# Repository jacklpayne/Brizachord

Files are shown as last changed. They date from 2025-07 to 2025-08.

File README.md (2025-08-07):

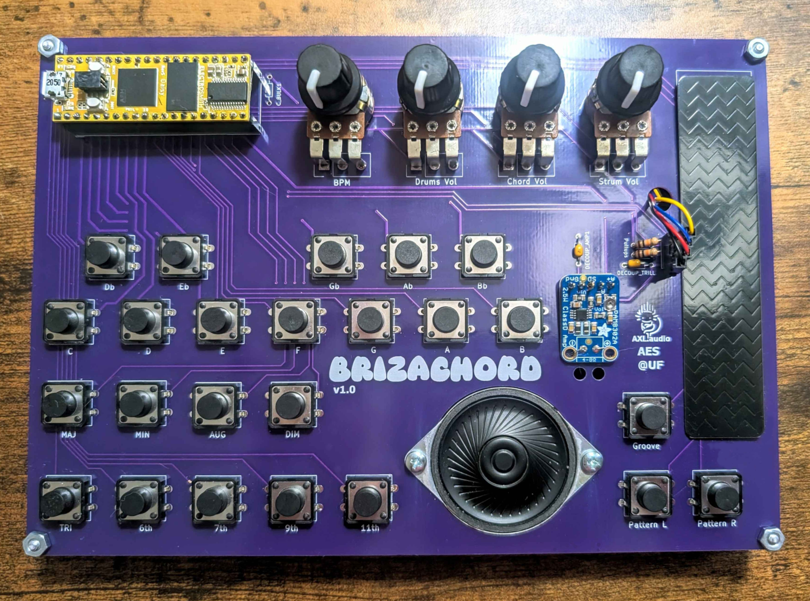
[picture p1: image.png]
Brizachord

Demo: https://www.youtube.com/watch?v=z-tGAeBtxNY

# Overview
The Brizachord is an open-source instrument and chord machine inspired by the Suzuki Omnichord. It features:
* 240 possible chords from 12 root select switches, 4 quality select switches, and 5 extension select switches
* Drum machine triggered by internal sequencer with toggleable chord pattern synchronization ("Groove"), adjustable BPM
* Velocity sensitive, multitouch capacitive strum plate for autoharp-style use
* Self-contained design with its own digital oscillators, amplification, and speaker (i.e, *not* a MIDI-only type deal).

It was designed by me and will be used in workshops held with the Audio Engineering Society at the University of Florida in Fall 2025.

# Technical
The instrument is based on the Daisy Seed audio development board and the associated `libdaisy` library for programming its STM32H7 MCU. It uses a Bela Trill Bar sensor for the strum plate and an Adafruit PAM8302A Class-D breakout for the amplifier. 

The hardware is designed for removability and reuse of the Daisy Seed and the Trill Bar.

# Future
## Software:
* Improve documentation of all functions
* USB MIDI (important)
* MIDI clock synchronization
* Data-driven CSV reading for sequencer patterns so that users can create their own more easily

## Hardware:
* Adjust Trill Bar JST cutout position
* Change corner mounting holes to M3 sized
* Find 12mm switches that are compatible with large black/white circular & square bezels to use for root selects, pattern selects
* Remove unused speaker routing holes and move Trill Bar headers to bottom of board
* Onboard power is possible, but unlikely to be implemented by me on this iteration of the board

# Environment setup
The firmware is based on a custom fork of `libdaisy` that updates the language version to `C++17` and merges @giulomoro's Trill support PR (https://github.com/electro-smith/libDaisy/pull/657). When this PR is merged upstream, the project will probably migrate to standard `libdaisy`.

# License
All software/firmware is licensed under GPLv3.
All hardware (schematic, design) is licensed under CERN-OHL-S.

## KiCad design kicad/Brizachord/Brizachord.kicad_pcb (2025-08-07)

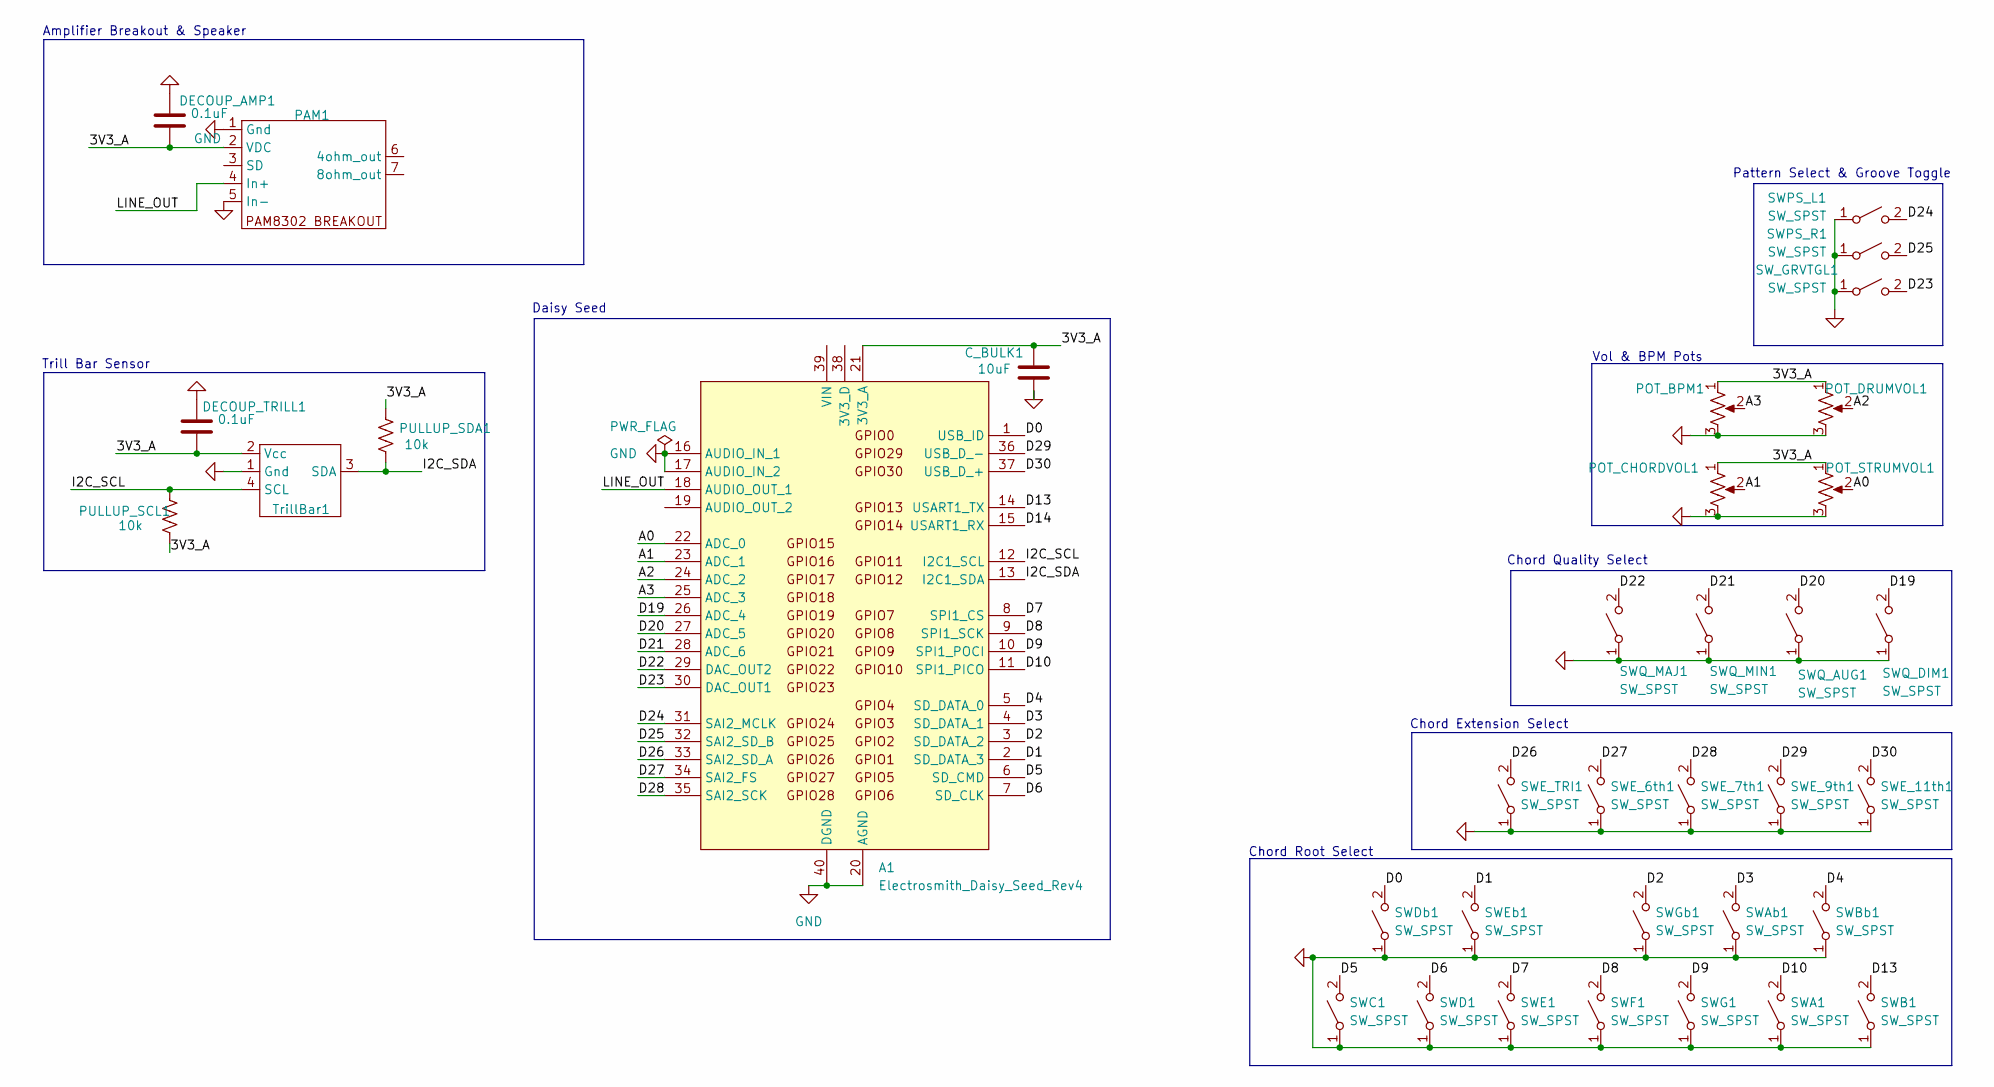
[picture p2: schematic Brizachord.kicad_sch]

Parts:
A1: Electrosmith_Daisy_Seed_Rev4; Electrosmith_Daisy_Seed
C_BULK1: 10uF; R_Axial_DIN0204_L3.6mm_D1.6mm_P7.62mm_Horizontal
DECOUP_AMP1: 0.1uF; R_Axial_DIN0204_L3.6mm_D1.6mm_P7.62mm_Horizontal
DECOUP_TRILL1: 0.1uF; R_Axial_DIN0204_L3.6mm_D1.6mm_P7.62mm_Horizontal
PAM1: PAM8302_BREAKOUT
POT_BPM1: R_Potentiometer_US; Samtec_HPM-03-01-x-S_Straight_1x03_Pitch5.08mm
POT_CHORDVOL1: R_Potentiometer_US; Samtec_HPM-03-01-x-S_Straight_1x03_Pitch5.08mm
POT_DRUMVOL1: R_Potentiometer_US; Samtec_HPM-03-01-x-S_Straight_1x03_Pitch5.08mm
POT_STRUMVOL1: R_Potentiometer_US; Samtec_HPM-03-01-x-S_Straight_1x03_Pitch5.08mm
PULLUP_SCL1: 10k; R_Axial_DIN0204_L3.6mm_D1.6mm_P5.08mm_Horizontal
PULLUP_SDA1: 10k; R_Axial_DIN0204_L3.6mm_D1.6mm_P5.08mm_Horizontal
SWA1: SW_SPST; SW_PUSH-12mm
SWAb1: SW_SPST; SW_PUSH-12mm
SWB1: SW_SPST; SW_PUSH-12mm
SWBb1: SW_SPST; SW_PUSH-12mm
SWC1: SW_SPST; SW_PUSH-12mm
SWD1: SW_SPST; SW_PUSH-12mm
SWDb1: SW_SPST; SW_PUSH-12mm
SWE1: SW_SPST; SW_PUSH-12mm
SWE_6th1, SWE_7th1, SWE_9th1, SWE_11th1: SW_SPST; SW_PUSH-12mm
SWE_TRI1: SW_SPST; SW_PUSH-12mm
SWEb1: SW_SPST; SW_PUSH-12mm
SWF1: SW_SPST; SW_PUSH-12mm
SWG1: SW_SPST; SW_PUSH-12mm
SWGb1: SW_SPST; SW_PUSH-12mm
SWPS_L1: SW_SPST; SW_PUSH-12mm
SWPS_R1: SW_SPST; SW_PUSH-12mm
SWQ_AUG1: SW_SPST; SW_PUSH-12mm
SWQ_DIM1: SW_SPST; SW_PUSH-12mm
SWQ_MAJ1: SW_SPST; SW_PUSH-12mm
SWQ_MIN1: SW_SPST; SW_PUSH-12mm
SW_GRVTGL1: SW_SPST; SW_PUSH-12mm
TrillBar1: PinHeader_1x04_P2.54mm_Vertical

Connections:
/3V3_A: A1.21 (3V3_A), C_BULK1.2, DECOUP_AMP1.1, DECOUP_TRILL1.1, PAM1.2 (VDC), POT_BPM1.1, POT_CHORDVOL1.1, POT_DRUMVOL1.1, POT_STRUMVOL1.1, PULLUP_SCL1.2, PULLUP_SDA1.1, TrillBar1.2 (Vcc)
/A0: A1.22 (ADC_0), POT_STRUMVOL1.2
/A1: A1.23 (ADC_1), POT_CHORDVOL1.2
/A2: A1.24 (ADC_2), POT_DRUMVOL1.2
/A3: A1.25 (ADC_3), POT_BPM1.2
/D0: A1.1 (USB_ID), SWDb1.2 (B)
/D1: A1.2 (SD_DATA_3), SWEb1.2 (B)
/D2: A1.3 (SD_DATA_2), SWGb1.2 (B)
/D3: A1.4 (SD_DATA_1), SWAb1.2 (B)
/D4: A1.5 (SD_DATA_0), SWBb1.2 (B)
/D5: A1.6 (SD_CMD), SWC1.2 (B)
/D6: A1.7 (SD_CLK), SWD1.2 (B)
/D7: A1.8 (SPI1_CS), SWE1.2 (B)
/D8: A1.9 (SPI1_SCK), SWF1.2 (B)
/D9: A1.10 (SPI1_POCI), SWG1.2 (B)
/D10: A1.11 (SPI1_PICO), SWA1.2 (B)
/D13: A1.14 (USART1_TX), SWB1.2 (B)
/D14: A1.15 (USART1_RX)
/D19: A1.26 (ADC_4), SWQ_DIM1.2 (B)
/D20: A1.27 (ADC_5), SWQ_AUG1.2 (B)
/D21: A1.28 (ADC_6), SWQ_MIN1.2 (B)
/D22: A1.29 (DAC_OUT2), SWQ_MAJ1.2 (B)
/D23: A1.30 (DAC_OUT1), SW_GRVTGL1.2 (B)
/D24: A1.31 (SAI2_MCLK), SWPS_L1.2 (B)
/D25: A1.32 (SAI2_SD_B), SWPS_R1.2 (B)
/D26: A1.33 (SAI2_SD_A), SWE_TRI1.2 (B)
/D27: A1.34 (SAI2_FS), SWE_6th1.2 (B)
/D28: A1.35 (SAI2_SCK), SWE_7th1.2 (B)
/D29: A1.36 (USB_D_-), SWE_9th1.2 (B)
/D30: A1.37 (USB_D_+), SWE_11th1.2 (B)
/I2C_SCL: A1.12 (I2C1_SCL), PULLUP_SCL1.1, TrillBar1.4 (SCL)
/I2C_SDA: A1.13 (I2C1_SDA), PULLUP_SDA1.2, TrillBar1.3 (SDA)
/LINE_OUT: A1.18 (AUDIO_OUT_1), PAM1.4 (In+)
GND: A1.16 (AUDIO_IN_1), A1.17 (AUDIO_IN_2), A1.20 (AGND), A1.40 (DGND), C_BULK1.1, DECOUP_AMP1.2, DECOUP_TRILL1.2, PAM1.1 (Gnd), PAM1.5 (In-), POT_BPM1.3, POT_CHORDVOL1.3, POT_DRUMVOL1.3, POT_STRUMVOL1.3, SWA1.1 (A), SWAb1.1 (A), SWB1.1 (A), SWBb1.1 (A), SWC1.1 (A), SWD1.1 (A), SWDb1.1 (A), SWE1.1 (A), SWE_6th1.1 (A), SWE_7th1.1 (A), SWE_9th1.1 (A), SWE_11th1.1 (A), SWE_TRI1.1 (A), SWEb1.1 (A), SWF1.1 (A), SWG1.1 (A), SWGb1.1 (A), SWPS_L1.1 (A), SWPS_R1.1 (A), SWQ_AUG1.1 (A), SWQ_DIM1.1 (A), SWQ_MAJ1.1 (A), SWQ_MIN1.1 (A), SW_GRVTGL1.1 (A), TrillBar1.1 (Gnd)

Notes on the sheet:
Chord Extension Select
Chord Quality Select
Vol & BPM Pots
Daisy Seed
Trill Bar Sensor
Chord Root Select
Pattern Select & Groove Toggle
Amplifier Breakout & Speaker

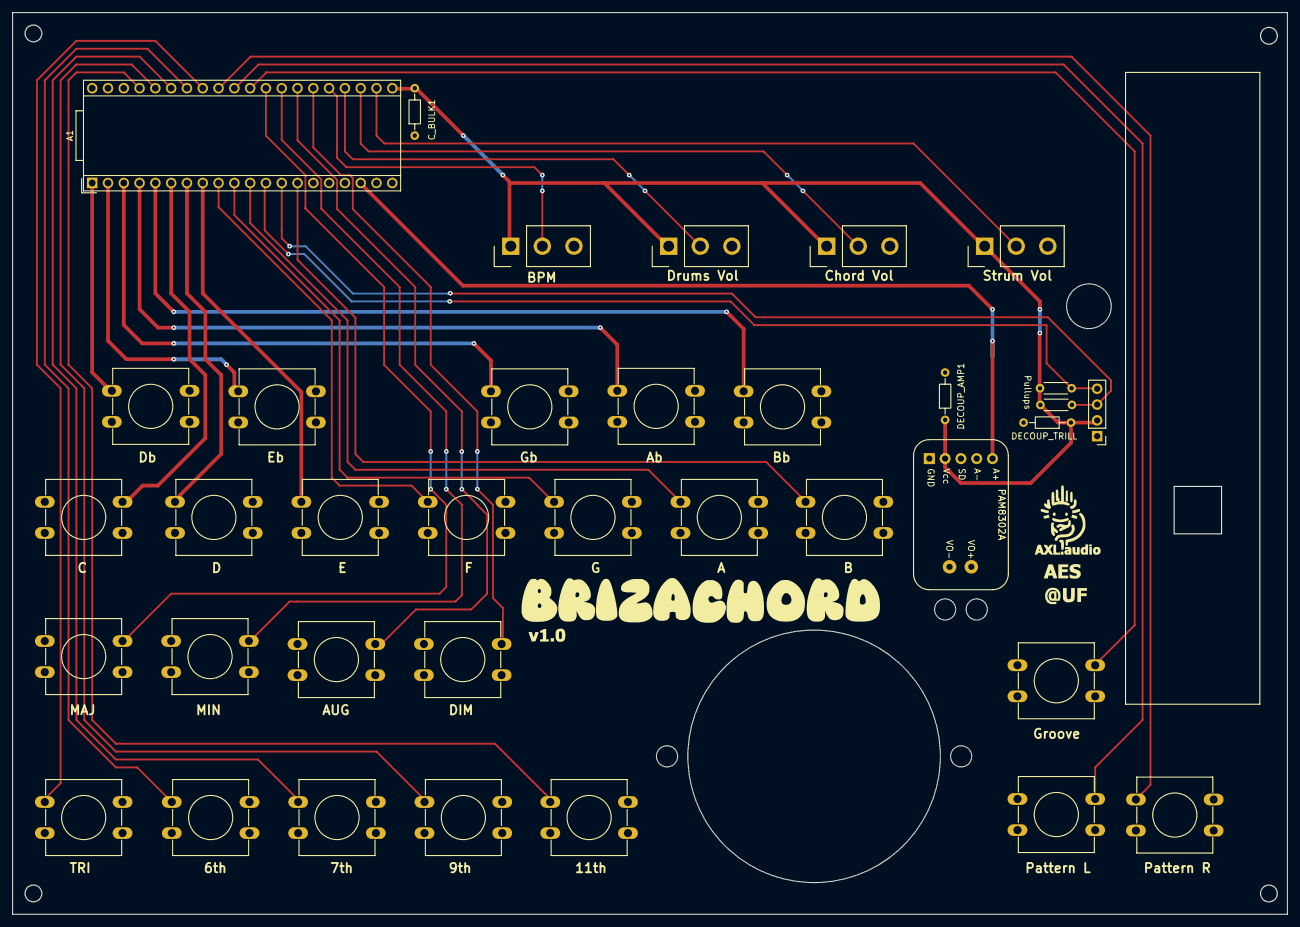
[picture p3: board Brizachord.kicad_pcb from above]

Board: 2 copper layers, 205.0 x 145.0 mm, 36 parts (0 on the bottom side), 33 nets.

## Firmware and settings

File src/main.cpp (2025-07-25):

/*
GNU General Public License v3.0
Author: Jack Payne

 _______             __                                __                                  __ 
/       \           /  |                              /  |                                /  |
BBBBBBB  |  ______  BB/  ________   ______    _______ BB |____    ______    ______    ____BB |
BB |__BB | /      \ /  |/        | /      \  /       |BB      \  /      \  /      \  /    BB |
BB    BB< /BBBBBB  |BB |BBBBBBBB/  BBBBBB  |/BBBBBBB/ BBBBBBB  |/BBBBBB  |/BBBBBB  |/BBBBBBB |
BBBBBBB  |BB |  BB/ BB |  /  BB/   /    BB |BB |      BB |  BB |BB |  BB |BB |  BB/ BB |  BB |
BB |__BB |BB |      BB | /BBBB/__ /BBBBBBB |BB \_____ BB |  BB |BB \__BB |BB |      BB \__BB |
BB    BB/ BB |      BB |/BB      |BB    BB |BB       |BB |  BB |BB    BB/ BB |      BB    BB |
BBBBBBB/  BB/       BB/ BBBBBBBB/  BBBBBBB/  BBBBBBB/ BB/   BB/  BBBBBB/  BB/        BBBBBBB/	v1.0
*/

#include "Brizachord.h"

int main(void) {
	Brizachord brizachord{};
	brizachord.main_loop();
}

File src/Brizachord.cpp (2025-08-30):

/*
GNU General Public License v3.0
Author: Jack Payne

 _______             __                                __                                  __ 
/       \           /  |                              /  |                                /  |
BBBBBBB  |  ______  BB/  ________   ______    _______ BB |____    ______    ______    ____BB |
BB |__BB | /      \ /  |/        | /      \  /       |BB      \  /      \  /      \  /    BB |
BB    BB< /BBBBBB  |BB |BBBBBBBB/  BBBBBB  |/BBBBBBB/ BBBBBBB  |/BBBBBB  |/BBBBBB  |/BBBBBBB |
BBBBBBB  |BB |  BB/ BB |  /  BB/   /    BB |BB |      BB |  BB |BB |  BB |BB |  BB/ BB |  BB |
BB |__BB |BB |      BB | /BBBB/__ /BBBBBBB |BB \_____ BB |  BB |BB \__BB |BB |      BB \__BB |
BB    BB/ BB |      BB |/BB      |BB    BB |BB       |BB |  BB |BB    BB/ BB |      BB    BB |
BBBBBBB/  BB/       BB/ BBBBBBBB/  BBBBBBB/  BBBBBBB/ BB/   BB/  BBBBBB/  BB/        BBBBBBB/	v1.0
*/

#include "Brizachord.h"
Brizachord* Brizachord::instance = nullptr;

Brizachord::Brizachord() 
	: strum_synth(48000.f, instrument_state), sequencer(48000.f, drum_synth, chord_synth)
{
    Brizachord::instance = this;

	// Hardware init
	hw.Configure();
	hw.Init();
	hw.SetAudioBlockSize(4);
	hw.SetAudioSampleRate(SaiHandle::Config::SampleRate::SAI_48KHZ);

	// Analog inputs init
	AdcChannelConfig adc_config[4];
	adc_config[0].InitSingle(hw.GetPin(15)); // A0 (Strum vol)
    adc_config[1].InitSingle(hw.GetPin(16)); // A1 (Chord vol)
    adc_config[2].InitSingle(hw.GetPin(17)); // A2 (Drums vol)
    adc_config[3].InitSingle(hw.GetPin(18)); // A3 (BPM)
	hw.adc.Init(adc_config, 4);
	hw.adc.Start();

	gpio_state.init();

	// Instrument state and oscillators init
	instrument_state.chord.root = "Bb";
	instrument_state.chord.quality = ChordQuality::MAJOR;
	instrument_state.chord.extension = ChordExtension::TRIAD;
	instrument_state.queued_extension = ChordExtension::TRIAD;
	instrument_state.queued_quality = ChordQuality::MAJOR;

	instrument_state.bpm = 80;

	auto midi_notes = chord_to_midi(instrument_state.chord);
	chord_synth.set_chord(instrument_state.chord);
	//strum_synth.set_arpeggio(midi_notes);

	poll_trill_bar();
	gpio_state.debounce_all();
	poll_chord_qual();
	poll_chord_ext();
	poll_chord_root();
	poll_pots();
	poll_pattern_controls();

	sequencer.set_bpm(instrument_state.bpm);

	hw.StartAudio(audio_callback);

	// Trill sensor setup
	// Reset I2C
    int i2cBus = 1;
    trill_bar.setup(i2cBus, Trill::BAR);
}

Brizachord::~Brizachord(){

}

void Brizachord::main_loop() {
	while(1) {
		poll_trill_bar();
		gpio_state.debounce_all();
		poll_chord_qual();
		poll_chord_ext();
		poll_chord_root();
		poll_pots();
		poll_pattern_controls();

		sequencer.set_bpm(instrument_state.bpm);
	}    
}

//======================================================================
// Main callback
//======================================================================
/* 
This callback is called every sample and:
1. Ticks the sequencer forward in time
2. Collects a sample from each of the three sound sources (chord synth, strum synth, and drums)
3. Scales them in proportion to user-set volumes and adds them together
4. Sends the resulting sample to Daisy Seed's audio output pin
*/
void Brizachord::audio_callback(AudioHandle::InputBuffer  in,
                                AudioHandle::OutputBuffer out,
                                size_t                    size) {
	
	for (size_t i = 0; i < size; i++)
	{	
		instance->sequencer.tick();
		float sample = 0.f;
		
		float chord_sample = instance->chord_synth.process();
		float drums_sample = instance->drum_synth.process();
		float strum_sample = instance->strum_synth.process();


		sample += drums_sample * 0.2f * instance->drum_vol;
		sample += chord_sample * 0.2f * instance->chord_vol;
		sample += strum_sample * 0.6f * instance->strum_vol;

		out[0][i] = sample;
		out[1][i] = sample;
	}
}

//======================================================================
// Polling
//======================================================================

/* Poll the chord root switches for changes. Update InstrumentState's chord root on a falling edge (press).*/
void Brizachord::poll_chord_root() {
    std::string new_root = instrument_state.chord.root;
	
	if      (gpio_state.button_C.FallingEdge())     new_root = "C";
	else if (gpio_state.button_Db.FallingEdge())    new_root = "Db";
	else if (gpio_state.button_D.FallingEdge())     new_root = "D";
	else if (gpio_state.button_Eb.FallingEdge())    new_root = "Eb";
	else if (gpio_state.button_E.FallingEdge())     new_root = "E";
	else if (gpio_state.button_F.FallingEdge())     new_root = "F";
	else if (gpio_state.button_Gb.FallingEdge())    new_root = "Gb";
	else if (gpio_state.button_G.FallingEdge())     new_root = "G";
	else if (gpio_state.button_Ab.FallingEdge())    new_root = "Ab";
	else if (gpio_state.button_A.FallingEdge())     new_root = "A";
	else if (gpio_state.button_Bb.FallingEdge())    new_root = "Bb";
	else if (gpio_state.button_B.FallingEdge())     new_root = "B";
	else                           return;

	if (new_root != instrument_state.chord.root) {
		instrument_state.chord.root = new_root;
		instrument_state.chord.quality = instrument_state.queued_quality;
		instrument_state.chord.extension = instrument_state.queued_extension;

		// Prevent audio ISR from being called while rebuilding the osc vectors
		__disable_irq();
		auto midi_notes = chord_to_midi(instrument_state.chord);
		chord_synth.set_chord(instrument_state.chord);
		strum_synth.set_arpeggio(midi_notes);
		__enable_irq();
	}
	else {
		instrument_state.no_chord = !instrument_state.no_chord;
	}
}

/* 
Poll the chord quality switches for changes.
On falling edge (press): update the InstrumentState's queued chord quality.
On rising edge (release): update the InstrumentState's chord with its queued quality.
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

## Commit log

2025-07-29 Small sound tweaks
    Tweaks some filters
2025-07-29 Fix extension buttons
2025-07-31 Fix crash on startup
    Addresses crash on startup issue by replacing pointers with class members
    [Brizachord.cpp]
2025-08-07 Add hardware files
    Adds the Kicad project files to the repo
    [Brizachord-B_Cu.gbr, Brizachord-B_Mask.gbr, Brizachord-B_Paste.gbr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]
